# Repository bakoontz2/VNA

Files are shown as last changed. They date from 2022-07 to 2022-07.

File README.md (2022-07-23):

This a project to create a Vector Network Analyzer based on the EU1KY antenna tuner that can be reconfigured for different needs.  This material is copyrighted by Daniel Marks (KW4TI) and licensed under the Creative Commons License CC-BY-SA 4.0.  The software is licensed under the zlib license.  These are open source licenses that permit commercial use, modification and redistribution with attribution, and require licensees to assume all risk for using the copyrighted materials.

Currently what is on this github are the Kicad files for the VNA and the software.  The software uses the "stm32duino" extension to the Arduino IDE.  The Arduino IDE can be downloaded from

https://www.arduino.cc/en/Main/Software

The stm32duino software can be installed using the instructions on the stm32duino web site

https://github.com/rogerclarkmelbourne/Arduino_STM32/wiki/Installation

which involves (at this time) downloading the git archive for the stm32duino and placing it under the "hardware" folder in your Arduino folder.

There are several Arduino libraries that are required for the SI5351A frequency synthesizer chip, ILI9341 TFT display module, and XPT2046 touchscreen controller.  These are provided for your use under the "libraries" directory of this archive, but may not be the most recent versions.  You could copy these directories into the "libraries" folder in your Arduino directory.

---------------------------------

The VNA may be used with or without a touchscreen.  If a touchscreen it used, it should be compiled with the "VNA_TOUCHSCREEN" defined in VNA.h.  If you do not have a touchscreen, you can ground the pin PB13 and it will start up without a touchscreen, only appearing a USB CDC serial port device.  You can then type "HELP" to see the list of commands.

The touchscreen used is a 2.8" touchscreen with a SPI interface to the ILI9341 and XPT2046.  These are commonly available at a low price.  To connect it to the SPI interface connector header "J1" on the board, use a 14 pin IDC ribbon cable.

----

The STM32 doesn't ship with an Arduino bootloader installed. Here are some links to get that installed:

* https://m.youtube.com/watch?v=Myon8H111PQ&t=0s 
* https://www.sgbotic.com/index.php?dispatch=pages.view&page_id=48

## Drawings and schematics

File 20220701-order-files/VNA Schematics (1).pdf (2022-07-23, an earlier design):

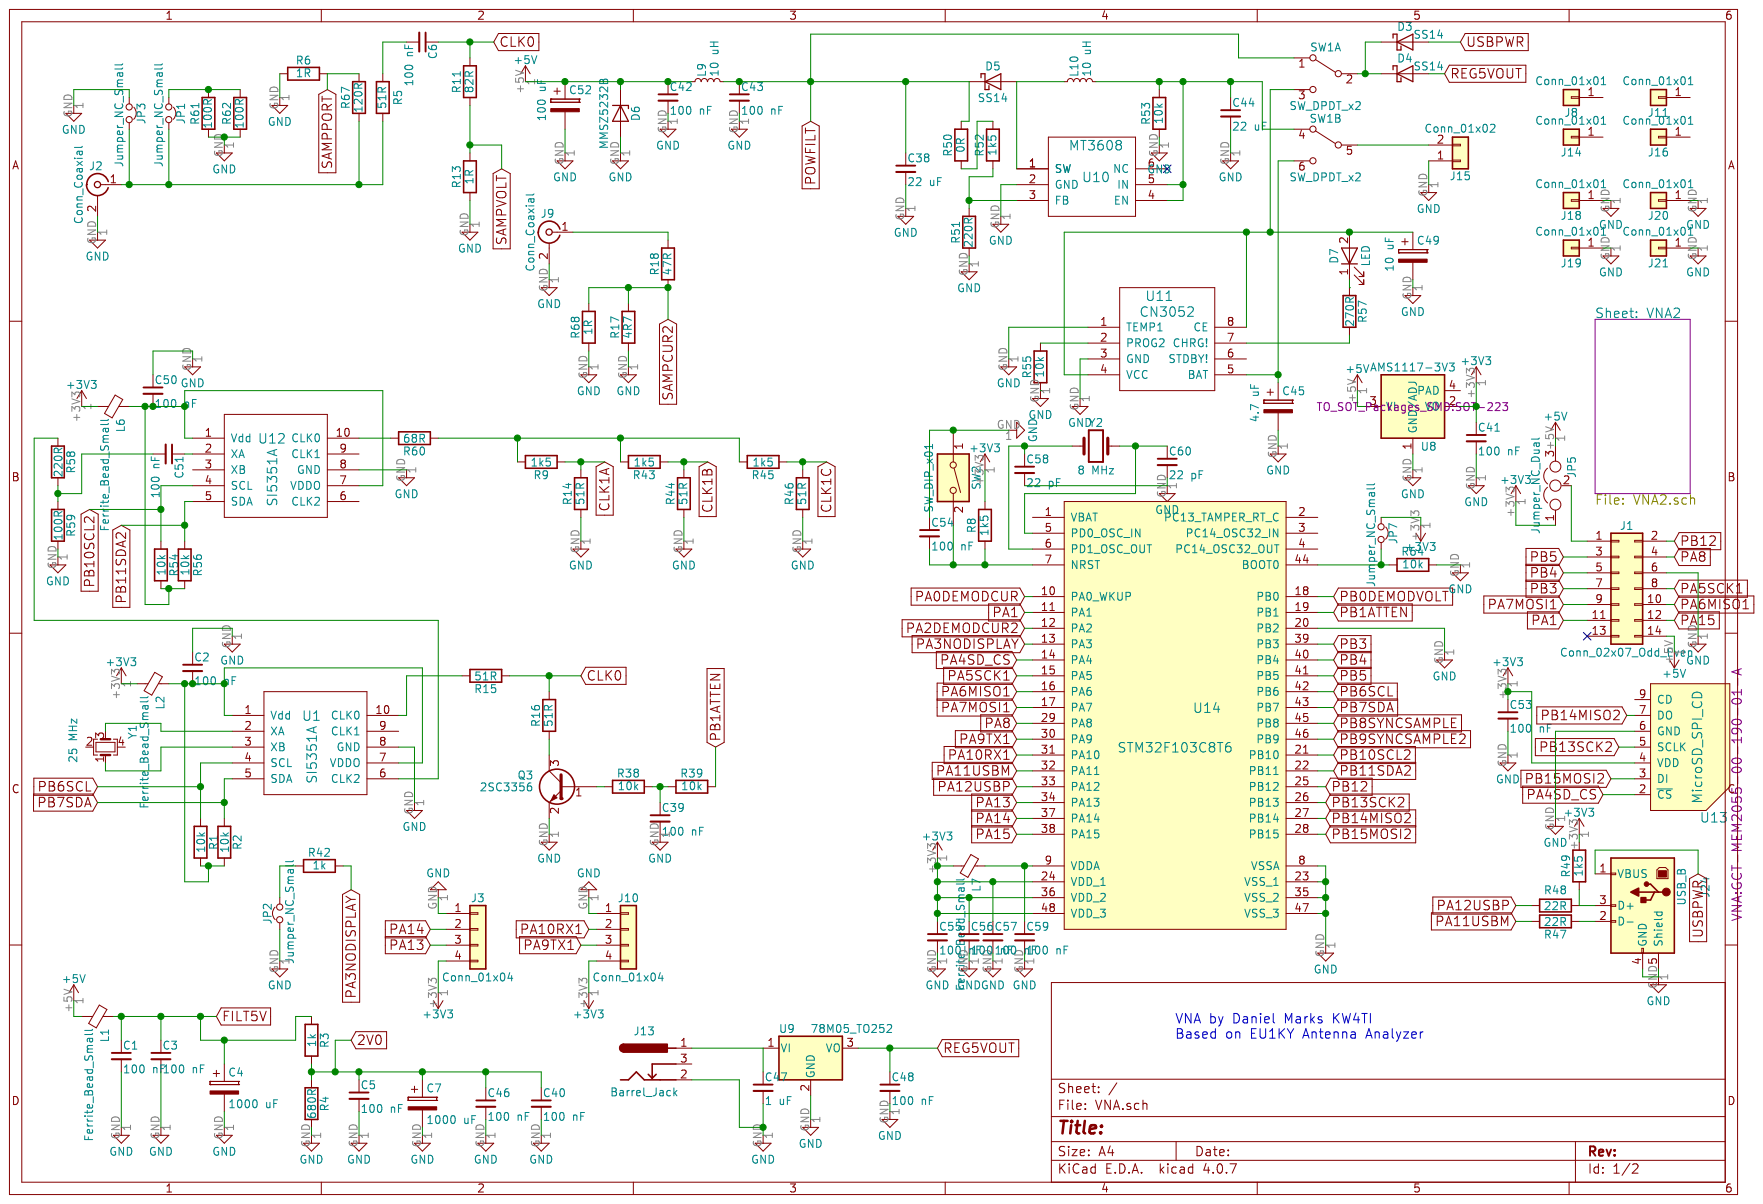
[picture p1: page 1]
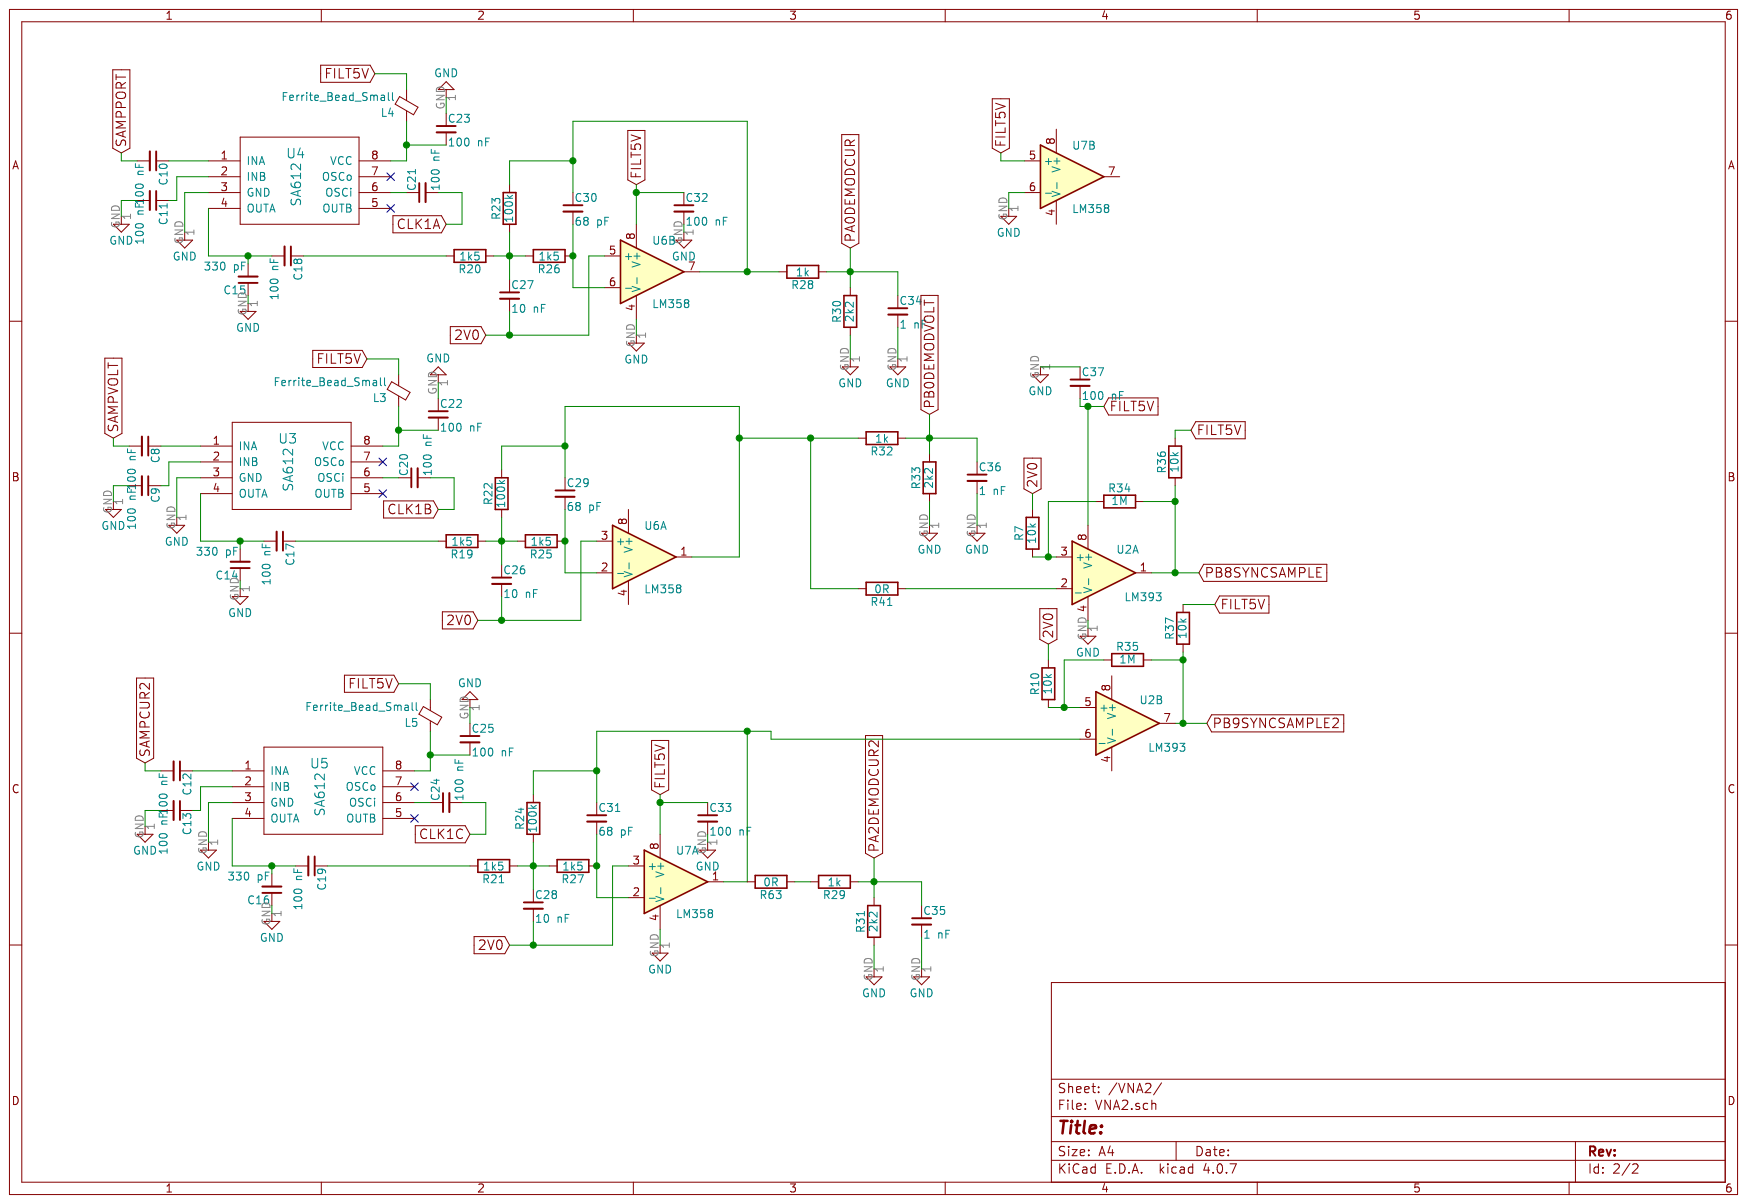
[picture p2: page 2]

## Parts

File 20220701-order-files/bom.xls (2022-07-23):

Comment | Designator | Footprint | JLCPCB Part #
GZ2012D101TF |  | Inductors_SMD:L_0805_HandSoldering | C1015
CL21B103KBANNNC |  | Capacitors_SMD:C_0805_HandSoldering | C1710
CL21C220JBANNNC |  | Capacitors_SMD:C_0805_HandSoldering | C1804
0805CG680J500NT |  | Capacitors_SMD:C_0805_HandSoldering | C1834
SS14 |  | Diodes_SMD:D_SMA | C2480
0805W8F1501T5E |  | Resistors_SMD:R_0805_HandSoldering | C4310
AMS1117-3.3 |  | TO_SOT_Packages_SMD:SOT-223 | C6186
LM393DR2G |  | Housings_SOIC:SOIC-8_3.9x4.9mm_Pitch1.27mm | C7955
ZMM5V6-M |  | Diodes_SMD:D_MiniMELF | C8062
STM32F103CBT6 |  | Housings_QFP:LQFP-48_7x7mm_Pitch0.5mm | C8304
X322525MOB4SI |  | Crystals:Crystal_SMD_3225-4pin_3.2x2.5mm_HandSoldering | C9006
2SC3356-T1B-A/AS |  | TO_SOT_Packages_SMD:SOT-23 | C9659
0805W8F1000T5E |  | Resistors_SMD:R_0805_HandSoldering | C17408
0805W8F1002T5E |  | Resistors_SMD:R_0805_HandSoldering | C17414
0805W8F1200T5E |  | Resistors_SMD:R_0805_HandSoldering | C17437
0805W8F0000T5E |  | Resistors_SMD:R_0805_HandSoldering | C17477
0805W8F1001T5E |  | Resistors_SMD:R_0805_HandSoldering | C17513
0805W8F1004T5E |  | Resistors_SMD:R_0805_HandSoldering | C17514
0805W8F2201T5E |  | Resistors_SMD:R_0805_HandSoldering | C17520
0805W8F2200T5E |  | Resistors_SMD:R_0805_HandSoldering | C17557
0805W8F220JT5E |  | Resistors_SMD:R_0805_HandSoldering | C17561
0805W8F2700T5E |  | Resistors_SMD:R_0805_HandSoldering | C17590
0805W8F470KT5E |  | Resistors_SMD:R_0805_HandSoldering | C17675
0805W8F470JT5E |  | Resistors_SMD:R_0805_HandSoldering | C17714
0805W8F510JT5E |  | Resistors_SMD:R_0805_HandSoldering | C17738
0805W8F6800T5E |  | Resistors_SMD:R_0805_HandSoldering | C17798
0805W8F680JT5E |  | Resistors_SMD:R_0805_HandSoldering | C17802
0805W8F820JT5E |  | Resistors_SMD:R_0805_HandSoldering | C17841
CN3052A |  | Housings_SOIC:TI_SO-PowerPAD-8 | C18772
0805W8F100KT5E |  | Resistors_SMD:R_0805_HandSoldering | C25271
CL21B105KBFNNNE |  | Capacitors_SMD:C_0805_HandSoldering | C28323
CL21B102KBCNNNC |  | Capacitors_SMD:C_0805_HandSoldering | C46653
CC0805KRX7R9BB104 |  | Capacitors_SMD:C_0805_HandSoldering | C49678
CL21B331KBANNNC |  | Capacitors_SMD:C_0805_HandSoldering | C51207
L78M05ABDT-TR |  | TO_SOT_Packages_SMD:TO-252-3_TabPin2 | C58069
NCD0805R1 |  | LEDs:LED_0805 | C84256
X50328MSB2GI |  | Crystals:Crystal_SMD_5032-2pin_5.0x3.2mm_HandSoldering | C115962
GS8722-SR |  | Housings_SOIC:SOIC-8_3.9x4.9mm_Pitch1.27mm | C157708
MS5351M |  | Housings_SSOP:MSOP-10_3x3mm_Pitch0.5mm | C1509083

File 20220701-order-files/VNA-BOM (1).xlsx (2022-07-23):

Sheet: VNA
Comment | Designator | Footprint | LCSC
330 pF | C14,C15,C16 | Capacitors_SMD:C_0805_HandSoldering | C51207
10 nF | C26,C27,C28 | Capacitors_SMD:C_0805_HandSoldering | C1710
100 nF | C1,C2,C3,C5,C6,C8,C9,C10,C11,C12,C13,C17,C18,C19,C20,C21,C22,C23,C24,C25,C32,C33,C37,C39,C40,C41,C42,C43,C46,C48,C50,C51,C53,C54,C55,C56,C57,C59 | Capacitors_SMD:C_0805_HandSoldering | C49678
68 pF | C29,C30,C31 | Capacitors_SMD:C_0805_HandSoldering | C1834
1 nF | C34,C35,C36 | Capacitors_SMD:C_0805_HandSoldering | C46653
22 uF | C38,C44 | Capacitors_SMD:C_1210_HandSoldering |  | x
1000 uF | C4,C7 | Capacitors_SMD:CP_Elec_8x10.5 |  | x
4.7 uF | C45 | Capacitors_SMD:CP_Elec_4x4.5 |  | x
1 uF | C47 | Capacitors_SMD:C_0805_HandSoldering | C28323
10 uF | C49 | Capacitors_SMD:CP_Elec_4x4.5 |  | x
100 uF | C52 | Capacitors_SMD:CP_Elec_4x4.5 |  | x
22 pF | C58,C60 | Capacitors_SMD:C_0805_HandSoldering | C1804
SS14 | D3,D4,D5 | Diodes_SMD:D_SMA | C2480
MMSZ5232B | D6 | Diodes_SMD:D_MiniMELF | C8062
LED | D7 | LEDs:LED_0805 | C84256
Conn_02x07_Odd_Even | J1 | Pin_Headers:Pin_Header_Straight_2x07_Pitch2.54mm
Conn_01x04 | J3,J10 | Pin_Headers:Pin_Header_Straight_1x04_Pitch2.54mm
Barrel_Jack | J13 | Connectors:BARREL_JACK
Conn_01x02 | J15 | Connectors_Molex:Molex_KK-6410-02_02x2.54mm_Straight
Conn_01x01 | J8,J11,J14,J16,J18,J19,J20,J21 | Connectors:1pin
Conn_Coaxial | J2,J9 | VNA:Amphenol_RF_SMA_132289
USB_B | J24 | Connectors:USB_B
Jumper_NC_Small | JP1,JP2,JP3,JP7 | Pin_Headers:Pin_Header_Straight_1x02_Pitch2.54mm
Jumper_NC_Dual | JP5 | Pin_Headers:Pin_Header_Straight_1x03_Pitch2.54mm
Ferrite_Bead_Small | L1,L2,L3,L4,L5,L6,L7 | Inductors_SMD:L_0805_HandSoldering | C1015
10 uH | L9,L10 | Inductors_SMD:L_7.3x7.3_H4.5
2SC3356 | Q3 | TO_SOT_Packages_SMD:SOT-23 | C9659
10k | R1,R2,R7,R10,R36,R37,R38,R39,R53,R54,R55,R56,R64 | Resistors_SMD:R_0805_HandSoldering | C17414
82R | R11 | Resistors_SMD:R_0805_HandSoldering | C17841
51R | R5,R14,R15,R16,R44,R46 | Resistors_SMD:R_0805_HandSoldering | C17738
4R7 | R17 | Resistors_SMD:R_0805_HandSoldering | C17675
47R | R18 | Resistors_SMD:R_0805_HandSoldering | C17714
100k | R22,R23,R24 | Resistors_SMD:R_0805_HandSoldering | C17407
1k | R3,R28,R29,R32,R42 | Resistors_SMD:R_0805_HandSoldering | C17513
2k2 | R30,R31,R33 | Resistors_SMD:R_0805_HandSoldering | C17520
1M | R34,R35 | Resistors_SMD:R_0805_HandSoldering | C17514
680R | R4 | Resistors_SMD:R_0805_HandSoldering | C17798
22R | R47,R48 | Resistors_SMD:R_0805_HandSoldering | C17561
0R | R41,R50,R63 | Resistors_SMD:R_0805_HandSoldering | C17477
220R | R51,R58 | Resistors_SMD:R_0805_HandSoldering | C17557
270R | R57 | Resistors_SMD:R_0805_HandSoldering | C17590
100R | R59,R61,R62 | Resistors_SMD:R_0805_HandSoldering | C17408
1R | R6,R13,R68 | Resistors_SMD:R_0805_HandSoldering | C25271
68R | R60 | Resistors_SMD:R_0805_HandSoldering | C17802
120R | R67 | Resistors_SMD:R_0805_HandSoldering | C17437
1k5 | R8,R9,R19,R20,R21,R25,R26,R27,R43,R45,R49,R52 | Resistors_SMD:R_0805_HandSoldering | C4310
SW_DPDT_x2 | SW1 | Connectors_Molex:Molex_KK-6410-06_06x2.54mm_Straight
SW_DIP_x01 | SW2 | Buttons_Switches_THT:SW_PUSH_6mm
SI5351A | U1,U12 | Housings_SSOP:MSOP-10_3x3mm_Pitch0.5mm
MT3608 | U10 | TO_SOT_Packages_SMD:SOT-23-6
CN3052 | U11 | Housings_SOIC:TI_SO-PowerPAD-8
MicroSD_SPI_CD | U13 | VNA:GCT-MEM2055-00-190-01-A
STM32F103C8T6 | U14 | Housings_QFP:LQFP-48_7x7mm_Pitch0.5mm | C8304
LM393 | U2 | Housings_SOIC:SOIC-8_3.9x4.9mm_Pitch1.27mm | C7955
SA612 | U3,U4,U5 | Housings_SOIC:SOIC-8_3.9x4.9mm_Pitch1.27mm
LM358 | U6,U7 | Housings_SOIC:SOIC-8_3.9x4.9mm_Pitch1.27mm | C7950
AMS1117-3V3 | U8 | TO_SOT_Packages_SMD:SOT-223 | C6186
78M05_TO252 | U9 | TO_SOT_Packages_SMD:TO-252-3_TabPin2 | C58069
25 MHz | Y1 | Crystals:Crystal_SMD_3225-4pin_3.2x2.5mm_HandSoldering | C9006
8 MHz | Y2 | Crystals:Crystal_SMD_5032-2pin_5.0x3.2mm_HandSoldering | C115962

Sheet: Digikey
Comment | Designator | Footprint | LCSC
22 uF | C38,C44 | Capacitors_SMD:C_1210_HandSoldering |  | x | 445-181602-1-ND
1000 uF | C4,C7 | Capacitors_SMD:CP_Elec_8x10.5 |  | x | 399-6705-1-ND
4.7 uF | C45 | Capacitors_SMD:CP_Elec_4x4.5 |  | x | 732-8449-1-ND
1 uF | C47 | Capacitors_SMD:C_0805_HandSoldering | C28323 |  | 2997-MA0805YV105Z250TR-ND
10 uF | C49 | Capacitors_SMD:CP_Elec_4x4.5 |  | x | 732-8385-1-ND
100 uF | C52 | Capacitors_SMD:CP_Elec_4x4.5 |  | x
10 uH | L9,L10 | Inductors_SMD:L_7.3x7.3_H4.5 |  |  | SRR0745A-100MCT-ND
100k | R22,R23,R24 | Resistors_SMD:R_0805_HandSoldering | C17407 |  | 1276-5576-1-ND
SA612 | U3,U4,U5 | Housings_SOIC:SOIC-8_3.9x4.9mm_Pitch1.27mm |  |  | 568-5045-1-ND
MT3608 | U10 | TO_SOT_Packages_SMD:SOT-23-6
Conn_02x07_Odd_Even | J1 | Pin_Headers:Pin_Header_Straight_2x07_Pitch2.54mm
Conn_01x04 | J3,J10 | Pin_Headers:Pin_Header_Straight_1x04_Pitch2.54mm
Barrel_Jack | J13 | Connectors:BARREL_JACK
Conn_01x02 | J15 | Connectors_Molex:Molex_KK-6410-02_02x2.54mm_Straight
Conn_01x01 | J8,J11,J14,J16,J18,J19,J20,J21 | Connectors:1pin
Conn_Coaxial | J2,J9 | VNA:Amphenol_RF_SMA_132289 |  |  | ACX1426-ND
USB_B | J24 | Connectors:USB_B |  |  | ED2983-ND
Display |  |  |  |  | 1528-1469-ND
MicroSD | U13 |  |  |  | 732-693071020811CT-ND

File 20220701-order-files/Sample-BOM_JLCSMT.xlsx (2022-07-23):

Comment | Designator | Footprint | JLCPCB Part #（optional）
100uF | C1 | CAP-SMD_L3.5-W2.8 | C16133
15K | R5,R6 | R0603 | C22809
DC-005-20A_C136744 | DC1 | DC-IN-TH_DC-005-20A | C136744
Header-Female-2.54_1x8 | P2,P3 | HDR-TH_8P-P2.54-V | C27438
K2-1102DP-C4SW-04 | SW1 | KEY-TH_4P-L6.0-W6.0-P4.50-LS6.5 | C110153
ATMEGA328P-PU | U1 | DIP-28_L34.6-W7.3-P2.54-LS10.2-BL | C33901
670688000 | USB1 | USB-B-TH_67068-8000 | C114097
